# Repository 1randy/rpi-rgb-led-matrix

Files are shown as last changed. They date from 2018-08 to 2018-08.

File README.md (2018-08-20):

# rpi-rgb-led-matrix
Raspberry Pi &amp; Dot Matrix LED Displays

Additional stuff used with [hzeller LED matrix library & software](https://github.com/hzeller/rpi-rgb-led-matrix)

## PCB adapter for Raspberry Pi to Hub75 RGB Matrixes
==================================================

Since hand-wiring can be a little tedious, here are some PCBs that help
with the wiring when using the `rpi-rgb-led-matrix` code.

   * [DMD-RaspberryPi](./DMD-RaspberryPi) active adapter board <br>
     Supports three parallel chains with active buffering
     and 3.3V -> 5V level shifting for best reliability. Requires SMD soldering.<br>
     EAGLE 7.x files, added WAGO 2060 cable clamp for powering the RPI.

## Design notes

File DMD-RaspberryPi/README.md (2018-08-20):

Adapter PCB to support up to 3 panel chains
===========================================

   * Supports up to three panel chains for newer plus models and
     Raspberry Pi 2 that have 40 GPIO pins.
   * Uses HCT245 to level shift signals from 3.3V to 5V and shield
     the Raspberry Pi GPIOs from overloading.
   * Optional: Pads to power the Pi with 5V, including optional capacitor footprints.
   * Provides a way to choose the pinout for different kinds of 64x64 matrixes.
   * BOM:
     - 4x 74HCT245 or 74AHCT245 in 20-SOIC, 7.5mm package which should make
     it easy to hand-solder. Make sure to get the variant with the **T**: HC**T** or AHC**T**
     (there are also HC or AHC, don't use these).
     - 4x 100nF ceramic capacitor (0805 package)
     - 1x 10kOhm resistor (0805 package). Not critcial, just a pullup (2.2k .. 15k probably ok).
     - 3x 16pin IDC (=2x8) male receptible to connect the panels.
     - 1x 40pin female connector to connect to the RPi.
     - 1x (optional) 22μF .. 100μF capacitor for 5V rail.
     - 1x (optional) WAGO 2060 Cable Clamp

## Layout
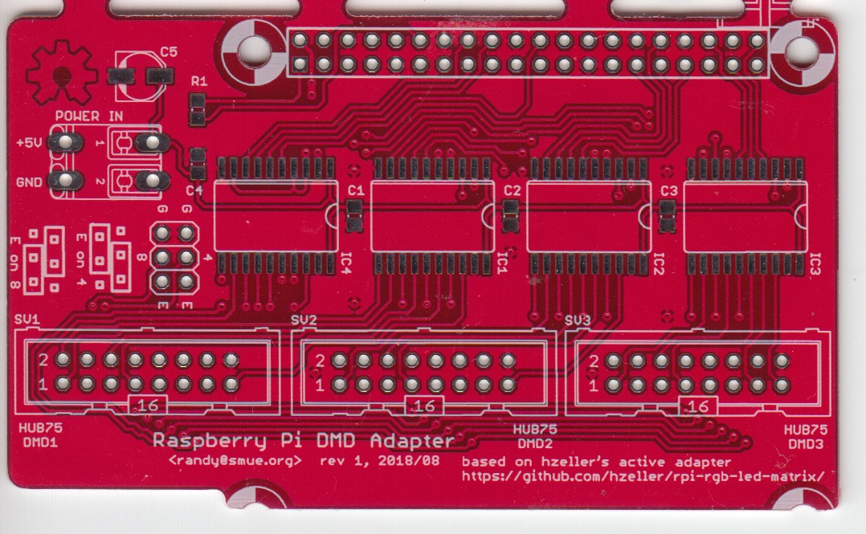
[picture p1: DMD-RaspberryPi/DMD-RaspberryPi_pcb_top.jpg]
pcb-top

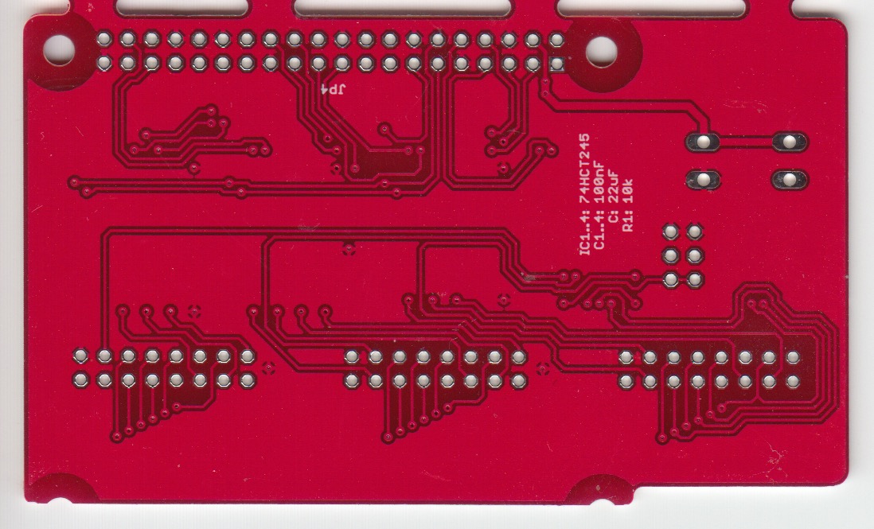
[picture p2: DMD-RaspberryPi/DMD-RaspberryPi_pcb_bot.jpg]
pcb-bot


## Schematic

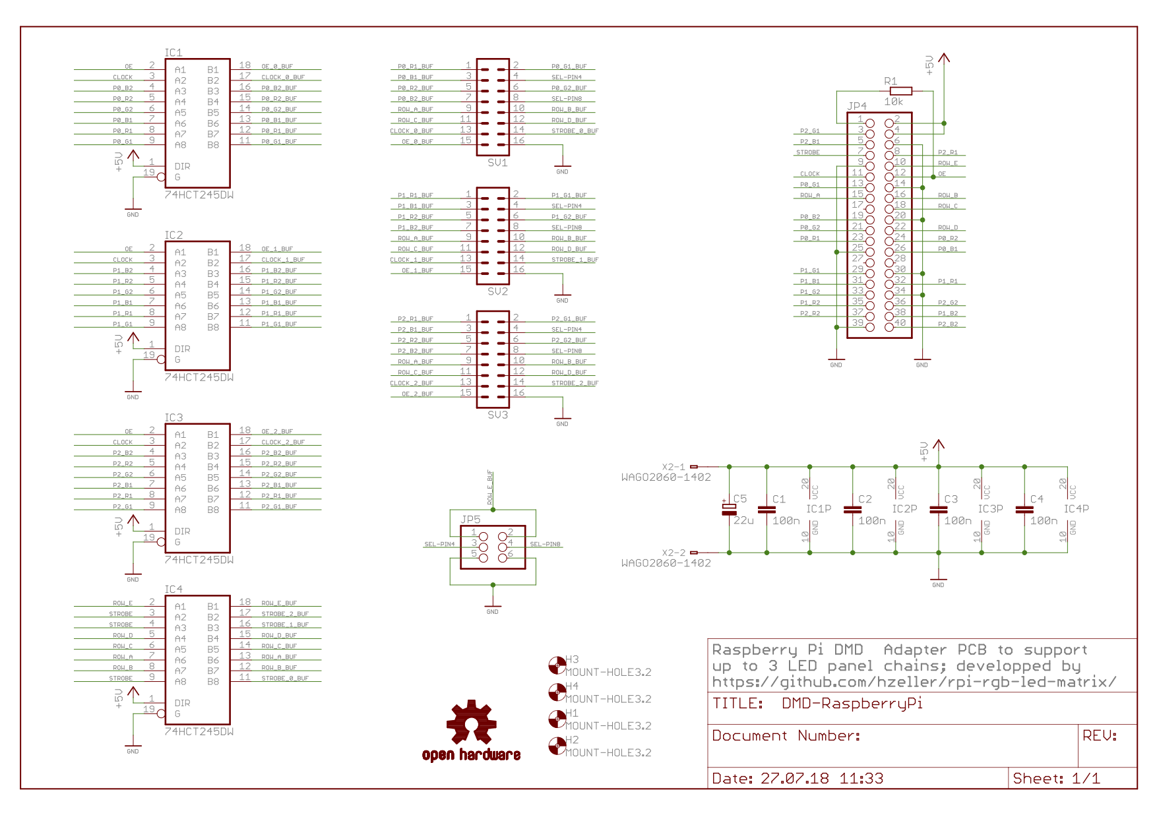
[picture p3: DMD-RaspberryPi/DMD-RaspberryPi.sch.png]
Schematic


[pcb-top]: ./DMD-RaspberryPi_pcb_top.jpg
[pcb-bot]: ./DMD-RaspberryPi_pcb_bot.jpg
[schematic]: ./DMD-RaspberryPi.sch.png

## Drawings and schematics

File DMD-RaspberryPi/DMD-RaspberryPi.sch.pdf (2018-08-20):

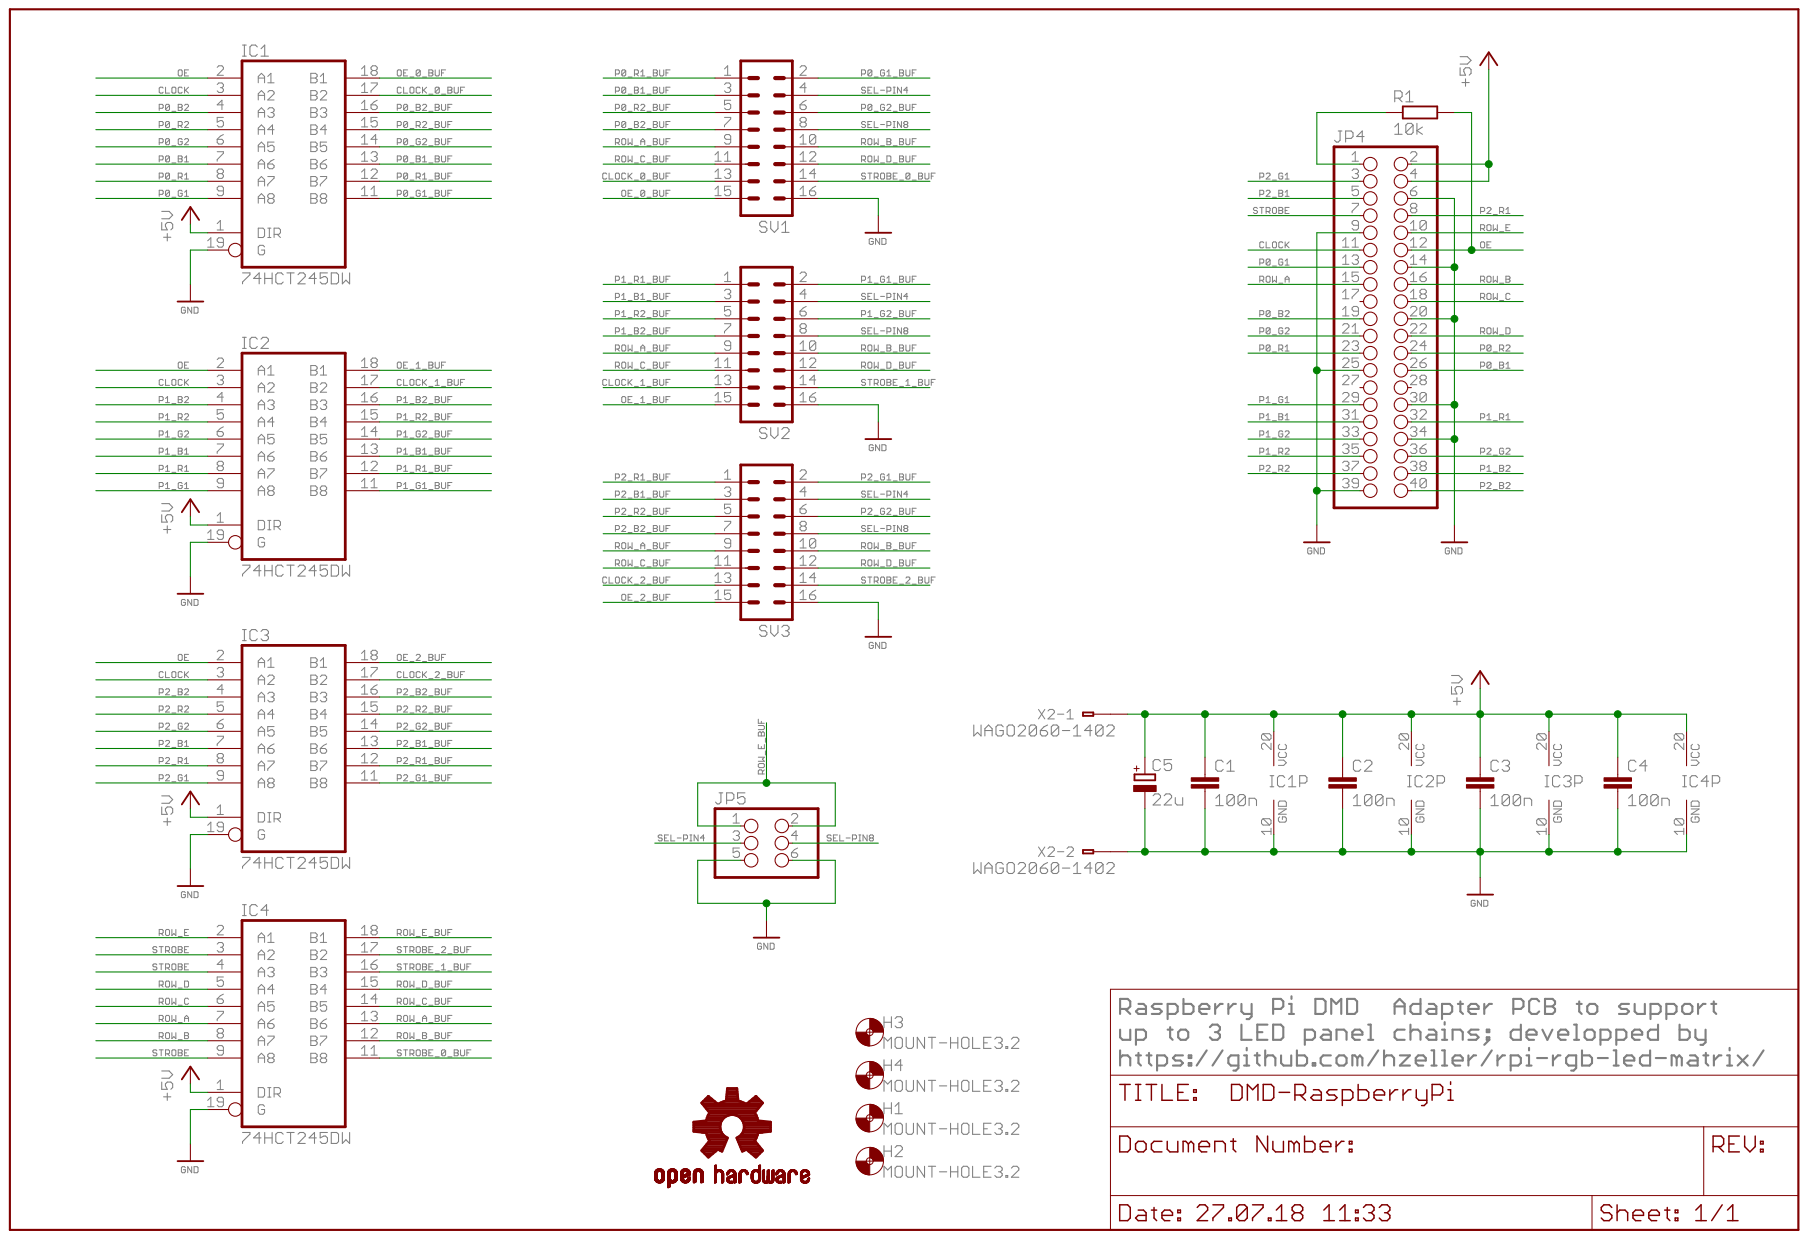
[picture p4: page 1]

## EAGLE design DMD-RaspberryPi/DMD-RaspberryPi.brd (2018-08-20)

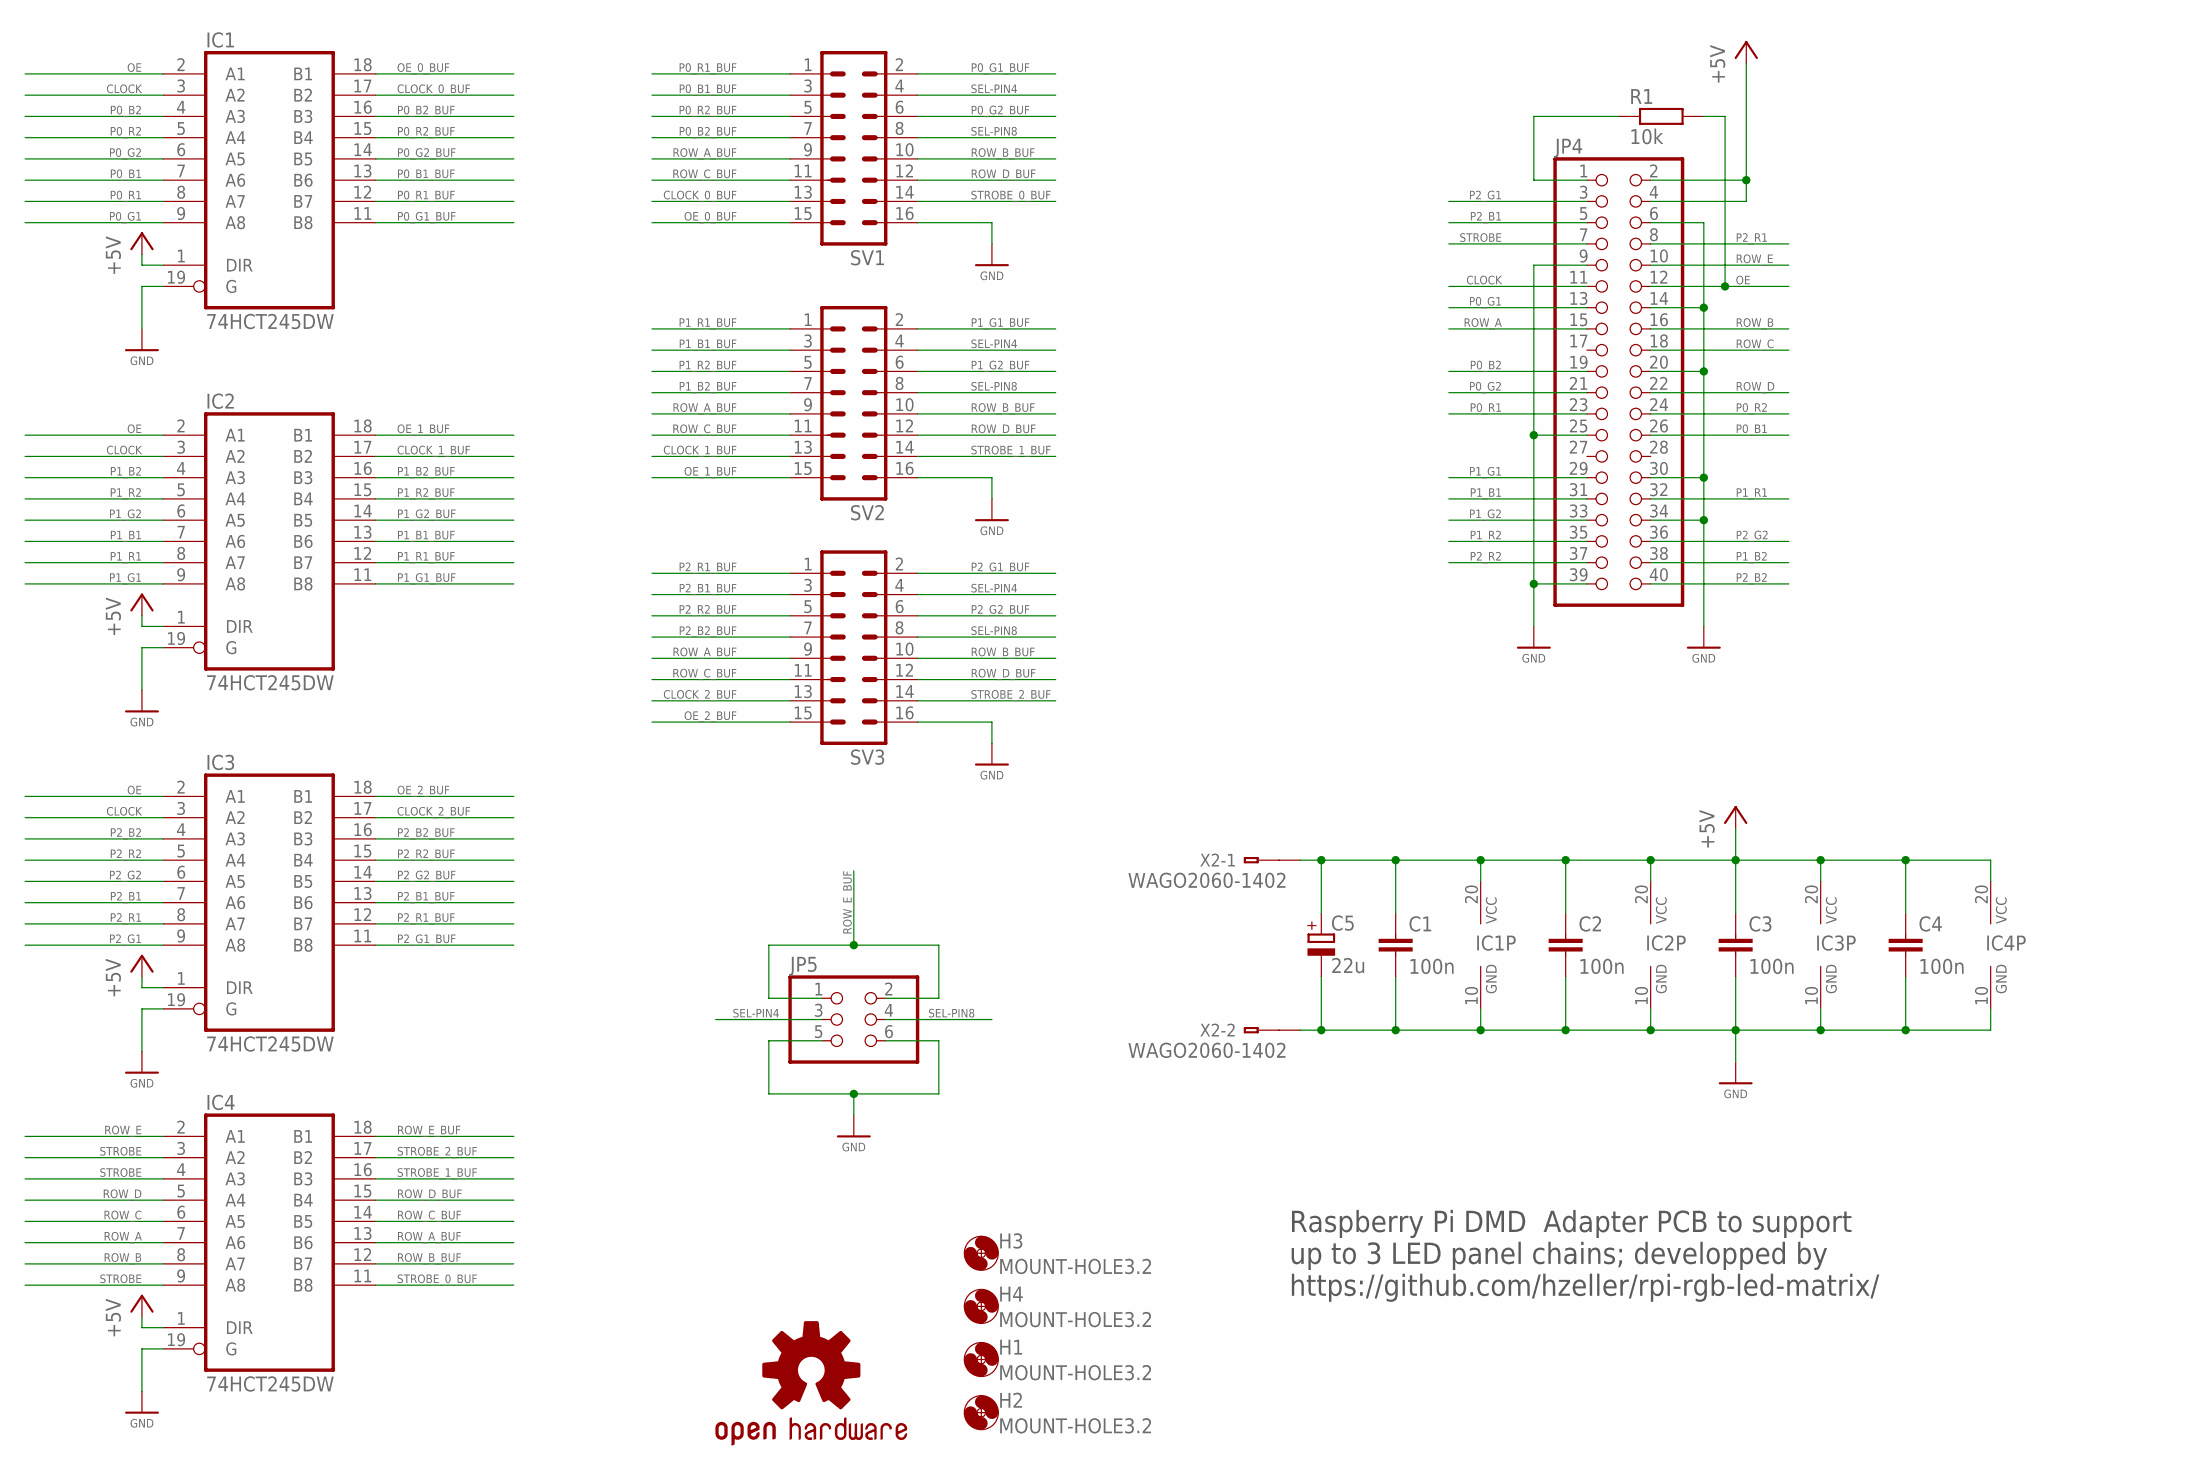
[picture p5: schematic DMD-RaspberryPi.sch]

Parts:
C1, C2, C3, C4: 100n; C0805
C5: 22u; PANASONIC_C
H1, H2, H3, H4: MOUNT-HOLE3.2; 3,2
IC1, IC2, IC3, IC4: 74HCT245DW; SO20W
JP4: PINHD-2X20; 2X20
JP5: PINHD-2X3; 2X03
LOGO1: OSHW-LOGOL-COPPER; OSHW-LOGO-L_COPPER
R1: 10k; R0805
SV1, SV2, SV3: ML16
X2: WAGO2060-1402; THT_RM4_2

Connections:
+5V: C1.1, C2.1, C3.1, C4.1, C5.+, IC1.1 (DIR), IC1.20 (VCC), IC2.1 (DIR), IC2.20 (VCC), IC3.1 (DIR), IC3.20 (VCC), IC4.1 (DIR), IC4.20 (VCC), JP4.2, JP4.4, X2.A2
CLOCK: IC1.3 (A2), IC2.3 (A2), IC3.3 (A2), JP4.11
CLOCK_0_BUF: IC1.17 (B2), SV1.13
CLOCK_1_BUF: IC2.17 (B2), SV2.13
CLOCK_2_BUF: IC3.17 (B2), SV3.13
GND: C1.2, C2.2, C3.2, C4.2, C5.-, IC1.10 (GND), IC1.19 (G), IC2.10 (GND), IC2.19 (G), IC3.10 (GND), IC3.19 (G), IC4.10 (GND), IC4.19 (G), JP4.6, JP4.9, JP4.14, JP4.20, JP4.25, JP4.30, JP4.34, JP4.39, JP5.5, JP5.6, SV1.16, SV2.16, SV3.16, X2.B2
unnamed: JP4.1, R1.1
OE: IC1.2 (A1), IC2.2 (A1), IC3.2 (A1), JP4.12, R1.2
OE_0_BUF: IC1.18 (B1), SV1.15
OE_1_BUF: IC2.18 (B1), SV2.15
OE_2_BUF: IC3.18 (B1), SV3.15
P0_B1: IC1.7 (A6), JP4.26
P0_B1_BUF: IC1.13 (B6), SV1.3
P0_B2: IC1.4 (A3), JP4.19
P0_B2_BUF: IC1.16 (B3), SV1.7
P0_G1: IC1.9 (A8), JP4.13
P0_G1_BUF: IC1.11 (B8), SV1.2
P0_G2: IC1.6 (A5), JP4.21
P0_G2_BUF: IC1.14 (B5), SV1.6
P0_R1: IC1.8 (A7), JP4.23
P0_R1_BUF: IC1.12 (B7), SV1.1
P0_R2: IC1.5 (A4), JP4.24
P0_R2_BUF: IC1.15 (B4), SV1.5
P1_B1: IC2.7 (A6), JP4.31
P1_B1_BUF: IC2.13 (B6), SV2.3
P1_B2: IC2.4 (A3), JP4.38
P1_B2_BUF: IC2.16 (B3), SV2.7
P1_G1: IC2.9 (A8), JP4.29
P1_G1_BUF: IC2.11 (B8), SV2.2
P1_G2: IC2.6 (A5), JP4.33
P1_G2_BUF: IC2.14 (B5), SV2.6
P1_R1: IC2.8 (A7), JP4.32
P1_R1_BUF: IC2.12 (B7), SV2.1
P1_R2: IC2.5 (A4), JP4.35
P1_R2_BUF: IC2.15 (B4), SV2.5
P2_B1: IC3.7 (A6), JP4.5
P2_B1_BUF: IC3.13 (B6), SV3.3
P2_B2: IC3.4 (A3), JP4.40
P2_B2_BUF: IC3.16 (B3), SV3.7
P2_G1: IC3.9 (A8), JP4.3
P2_G1_BUF: IC3.11 (B8), SV3.2
P2_G2: IC3.6 (A5), JP4.36
P2_G2_BUF: IC3.14 (B5), SV3.6
P2_R1: IC3.8 (A7), JP4.8
P2_R1_BUF: IC3.12 (B7), SV3.1
P2_R2: IC3.5 (A4), JP4.37
P2_R2_BUF: IC3.15 (B4), SV3.5
ROW_A: IC4.7 (A6), JP4.15
ROW_A_BUF: IC4.13 (B6), SV1.9, SV2.9, SV3.9
ROW_B: IC4.8 (A7), JP4.16
ROW_B_BUF: IC4.12 (B7), SV1.10, SV2.10, SV3.10
ROW_C: IC4.6 (A5), JP4.18
ROW_C_BUF: IC4.14 (B5), SV1.11, SV2.11, SV3.11
ROW_D: IC4.5 (A4), JP4.22
ROW_D_BUF: IC4.15 (B4), SV1.12, SV2.12, SV3.12
ROW_E: IC4.2 (A1), JP4.10
ROW_E_BUF: IC4.18 (B1), JP5.1, JP5.2
SEL-PIN4: JP5.3, SV1.4, SV2.4, SV3.4
SEL-PIN8: JP5.4, SV1.8, SV2.8, SV3.8
STROBE: IC4.3 (A2), IC4.4 (A3), IC4.9 (A8), JP4.7
STROBE_0_BUF: IC4.11 (B8), SV1.14
STROBE_1_BUF: IC4.16 (B3), SV2.14
STROBE_2_BUF: IC4.17 (B2), SV3.14

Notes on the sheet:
Raspberry Pi DMD Adapter PCB to support up to 3 LED panel chains; developped by https://github.com/hzeller/rpi-rgb-led-matrix/

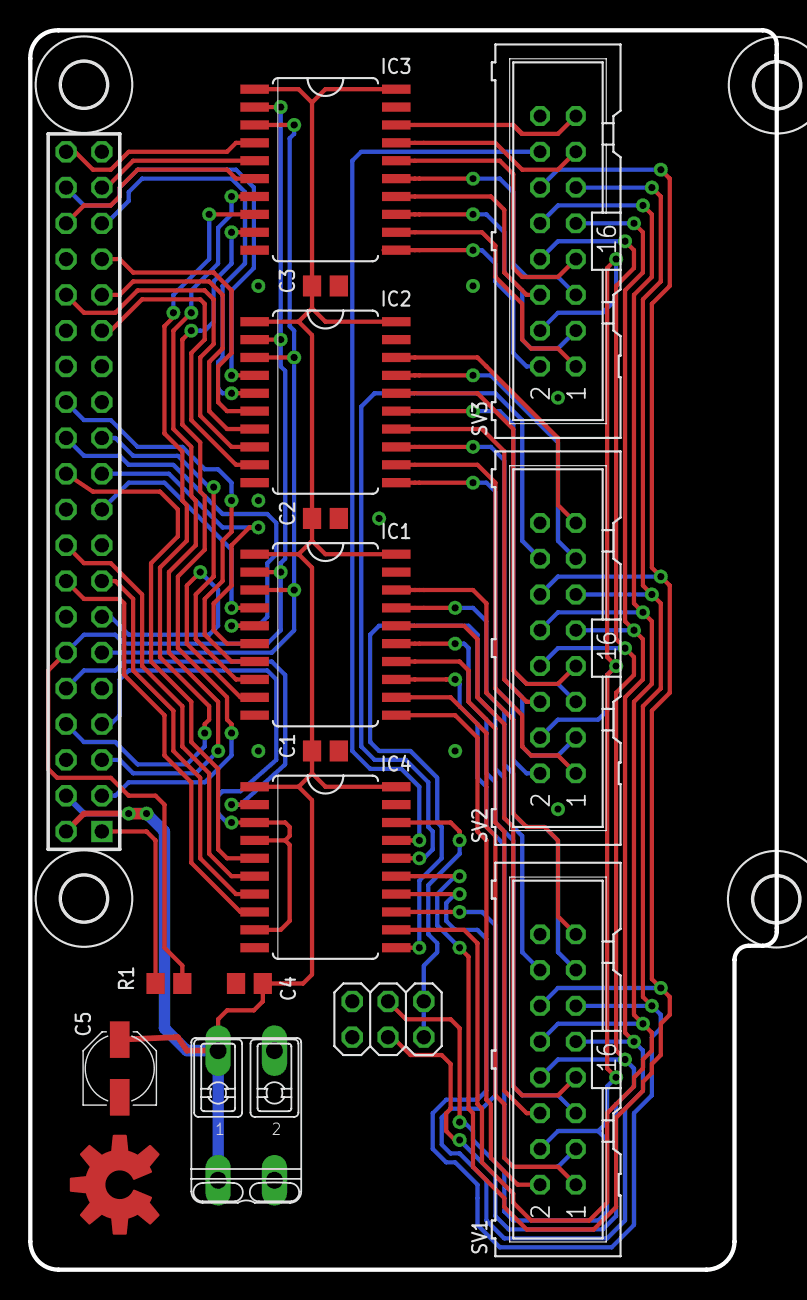
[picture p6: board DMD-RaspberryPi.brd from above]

Board: 2 copper layers, 53.0 x 88.0 mm, 21 parts (0 on the bottom side), 63 nets.

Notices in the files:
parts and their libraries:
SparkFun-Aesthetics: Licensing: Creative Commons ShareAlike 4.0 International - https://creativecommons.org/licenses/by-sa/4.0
